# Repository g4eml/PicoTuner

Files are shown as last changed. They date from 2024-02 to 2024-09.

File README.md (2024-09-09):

# PicoTuner
## Description

This design is for a Raspberry Pi Pico based USB interface for the BATC Minitiouner V3 Digital TV Receiver.
It is intended to replace the previously used FTDI FT2232H module which is expensive and sometimes difficult to obtain. 
The Raspberry Pi Pico is low cost, readily available and can also handle both Transport streams from the NIM module. 

## Requirements

This code will work on the original Raspberry Pi Pico, the Pico W, the Pico 2 and probably on other RP2040 and RP2350 based boards.
Whilst being designed for the new BATC V3 Minitiouner project it is also possible to retrofit a Pico to the V2 Minitiouner.
The advantage of doing this is to provide access to the second Transport Stream from the NIM. This will allow two signals to be received at the same time.

## Limitations

The Pico hardware can only support USB 1.1 Full Speed mode which is up to 12 Mb/s. The FTDI module can support High speed mode which is much faster. For this reason the Pico is only able to support the low Sample rate DVBS transmissions commonly used for amateur radio. It is not able to receive the much higher SRs used by commercial TV.  The upper speed limit has not yet been fully defined but it is perfectly capable of receiving the QO-100 (SR1500) Beacon twice, using both TS. 

## Programming or updating the Raspberry Pi Pico (quick method)

This can be done either before or after the Pico has been fitted to the minitiouner, it makes no difference. Updating to a new firmware version is done the same way. 

The uf2 file (from Version 0.12 onwards) is compatible with both the Pico and the Pico 2. 

1. Locate the latest compiled firmware file 'PicoTuner_vxxx.uf2' which will be found here https://github.com/g4eml/PicoTuner/releases and save it to your desktop. 

2. Hold down the BOOTSEL button on the Pico while connecting it to your PC using its micro USB port. The Pico should appear as a USB disk drive on your PC.

3. Copy the .uf2 file onto the USB drive. The pico will recognise the file and immediately update its firmware, reboot and the PC should recognise a new USB device. 

## Building your own version of the firmware (longer method and not normally required)
The Raspberry Pi Pico is programmed using the Arduino IDE with the Earl F. Philhower, III   core. 

#### Installing the Arduino IDE

1. Download and Install the Arduino IDE 2.3.0 from here https://www.arduino.cc/en/software

2. Open the Arduino IDE and go to File/Preferences.

3. in the dialog enter the following URL in the 'Additional Boards Manager URLs' field: https://github.com/earlephilhower/arduino-pico/releases/download/global/package__index.json

4. Hit OK to close the Dialog.

5. Go to Tools->Board->Board Manager in the IDE.

6. Type “pico” in the search box.

7. Locate the entry for 'Raspberry Pi Pico/ by Earle F. Philhower, III' and click 'Install'
 
#### Downloading the Software.

1. Download the latest released source code .zip file from https://github.com/g4eml/PicoTuner/releases

2. Save it to a convenient location and then unzip it. 

#### Programming the Pico

1. Open the Arduino IDE and click File/Open

2. Navigate to the File PicoTuner/Picotuner.ino (downloaded in the previous step) and click Open.

3. Select Tools and make the following settings.

   Board: "Raspberry Pi Pico" or "Raspberry Pi Pico 2"

   Debug Level: "None"

   Debug Port: "Disabled"

   C++ Exceptions: "Disabled"
   
   Flash Size: "2Mb (no FS)" for the Pico or "4Mb (no FS)" for the Pico 2
   
   CPU Speed: "133MHz" for the Pico or "150MHz" for the Pico 2

   IP/Bluetooth Stack: "IPV4 Only"
   
   Optimise: "Small (-Os)(standard)"
   
   RTTI: "Disabled"
   
   Stack Protection: "Disabled"

   Upload Method: "Default (UF2)"
   
   USB Stack: "No USB"          *** Yes this is correct, we don't need any additional USB support, it is all handled by the program. 

5. Connect the Rasperry Pi Pico to the USB port while holding down the BOOTSEL button. 

6. Click Sketch/Upload.

The Sketch should compile and upload automatically to the Pico. If the upload fails you may need to disconnect the Pico and then hold down the BOOTSEL button while reconnecting. 

## Firmware description

The firmware is based on the Raspberry Pi foundation example code for a low level USB device. It adds additional changes to the device descriptors so that the device configuration is very close to that of the previoulsy used FTDI2232 module.

Control of the GPIO pins for I2C, for device control and for reading the two TS streams is done using PIO state machines which are defined in the .pio.h files. 
Note that these files are auto generated and should not be manually edited. If you need to change the PIO machines then you will need to edit the .pio files and recompile them. 
The .pio files are not visible in the Arduino IDE, you should use another text editor to work on them. When finished you should run the 'build_pio.bat' batch job to create the pio.h files. 

Both cores of the  or RP2350 chip are used. Core0 does most of the work including running the interrupt driven USB device. Core1 handles the task of handling the DMA, copying and reformatting of the TS data.
Note that both cores are fairly time critical. Adding debugging print statements will slow them down and cause errors with the USB device. 

## USB device description

The resulting USB device has been made to look very similar to the FTDI FT2232H and presents two interfaces.  This is so that any existing software can easily be adapted to work with the new device. 
It is however far from a full emulation of the FT2232H. Only those features need by the Minitiuoner are implemented. Some FTDI commands are acknowledged but do nothing. 

The device VID is 0x2E8A (Raspberry Pi Foundation)

The device PID is 0xBA2C 

The endpoints are as follows:-

On Interface 0:-

0x00 and 0x80 as output and input for device control. 

0x81 and 0x02 for I2C and GPIO control. Very loosly emulating the FTDI MPSSE device

On Interface 1:-

0x83 and 0x84 as Bulk transfer inputs for streaming TS2 and TS1. Sent 512 bytes at a time. Note that there is a 2 byte status word at the beginning of each 512 byte transfer which will nedd to be removed to reform the original TS. 

## USB Drivers

No special drivers are needed for Ryde or Portsdown. If you are using the Picotuner with Windows then you will need to load the WinUSB drivers using the Zadig program which can be downloaded from https://github.com/pbatard/libwdi/releases/tag/v1.5.0

Using Zadig you can now install the WinUSB driver for both of the USB interfaces presented by the Pico.




Note that you must load the driver for Interface 0 and Interface 1  as shown above. 

Once the correct drivers have been loaded the picotuner should appear under 'Universal Serial Bus Devices' in windows hardware manager. 

PicoTuner in Device Manager

# Adaptor PCB for Minitiouner

Adaptor_Small

Whilst the PicoTuner was designed for use in a new tuner design it can also be retrofitted to the BATC V2 Minitiouner and similar designs providing their FTDI modules are fitted in sockets. This involves removing the FTDI module, replacing it with an adaptor pcb and adding 5 wires to connect signals that are not present on the FTDI sockets. The advantage of doing this upgrade is to provide access to the second TS. When supported by the host software this then allows the reception of two signals at the same time. To save space and to try to make the module mechanically compatible surface mount techniques are used. However due to the large size of the components involved it is still easily assembled by hand.  

## What is needed to make the adaptor

Parts Small

PCB :- These will be available from the BATC shop, or you can get your own made using one of the Chinese PCB manufacturers. The Gerber files are include in the Adaptor Folder.

Raspberry Pi Pico :- Surface mount version without pin headers.<br />
The Pi Hut Part Number:- SC0915    Mouser Part Number :- 358-SC0915

2 x 26 way Dual row 2.54mm surface mount pin headers.<br /> 
Harwin Part Number:- M20-8761346   Mouser Part Number:- 855-M20-8761346   Farnell Part Number :- 3756209

1 x 5 way Single row 2.54mm through hole pin header.<br /> 
Harwin Part Number:- M20-9990545   Mouser Part Number:- 855-M20-9990545   Farnell Part Number :- 1022252

## Assembly instructions

Start with fitting the first of the 26 Way Dual row pin headers. Apply solder to one pad of the PCB and then tack the connector in place. Ensure that all of the pins are centrally aligned on the pads. Once you are happy with the position apply solder to all af the pads to fix the connector in position. Fit the second connector in the same way, checking the the spacing is correct to fit into the socket on the minitiouner before final soldering. If you align both connectors accurately on the pads this will be correct but you may wish to use a scrap of veroboard or someting similar to check the alignment. Once you are happy solder the second connector into place.

Lay the pico board directly onto the PCB and align the edges with the pads. Apply solder to the castelated edge of pin 1 to form a fillet of solder. Check the alignment of the board and adjust as necessary. When happy apply solder to all castellated holes. If possible leave the driled holes free of solder. This will simplify the fitting of the Ethernet module at a later date. 

Fit and solder the 5 way pin header. 

Underside Small
Topside Small

## Fitting to the BATC V2 Minitiouner

Remove the FTDI module from its socket. Plug the Pico adaptor PCB in its place. The USB connector should be very close to the same position and should still be accessable through the rear panel. 

Connect pin 5 of J1 on the adaptor module to pin 9 of U7 (74HC10) on the minitiouner board. The 74HC10 is no longer used, so it can be removed or left in place, it makes no difference. You can solder the wire directly to the pin of the chip, remove the chip and plug the wire into the socket or use a pin header. 

Connect pin 4 of J1 to pin 10 of U7 in the same way. 

74HC10 Small

The final three wires need to be connected between J1 and the 'TS1' connector on the minitiouner PCB. These wires are only required if you wish to use the second TS. 

Connect J1 Pin 1 to D7

Connect J1 pin 2 to CLK

Connect J1 pin 3 to VA

TS1 Small
Fitting Small

## Programming the Pico

Program the pico as described [above](#programming-or-updating-the-raspberry-pi-pico-quick-method).

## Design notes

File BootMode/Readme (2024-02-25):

Version 0.8 adds a new command which will force the PicoTuner to enter BOOTSEL mode ready for uploading new firmware. 
This is as an altenative to using the BOOTSEL button on the Pico. Useful to avoid opening the case. 
New command is the single character 0xBB sent to Endpoint 2. The Pico will then immediately enter BOOTSEL  mode. 
A python script and a windows batch file are provided to send the necessary command.

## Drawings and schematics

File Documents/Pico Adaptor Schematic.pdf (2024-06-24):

# Raspberry Pi Pico Adaptor for Minitiouner V2 Boards

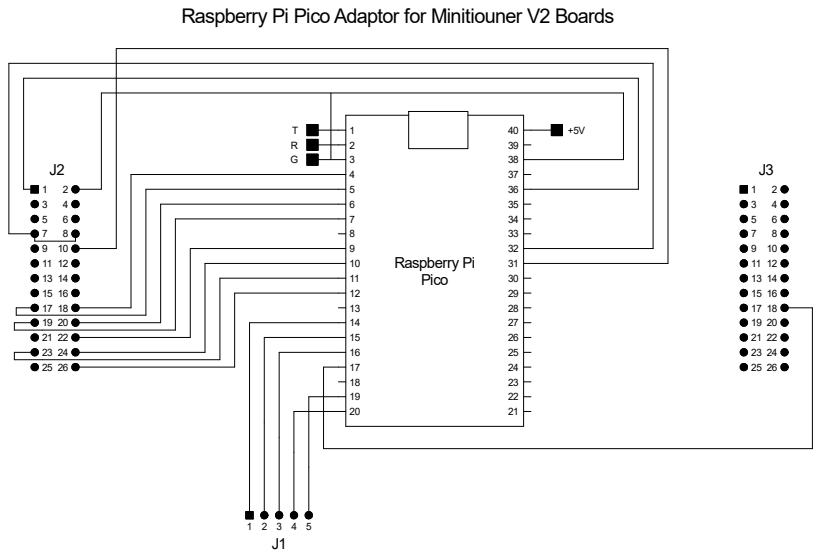
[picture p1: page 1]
Raspberry Pi Pico

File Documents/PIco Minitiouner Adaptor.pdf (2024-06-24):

## Pico Adaptor for Minitiouner V2

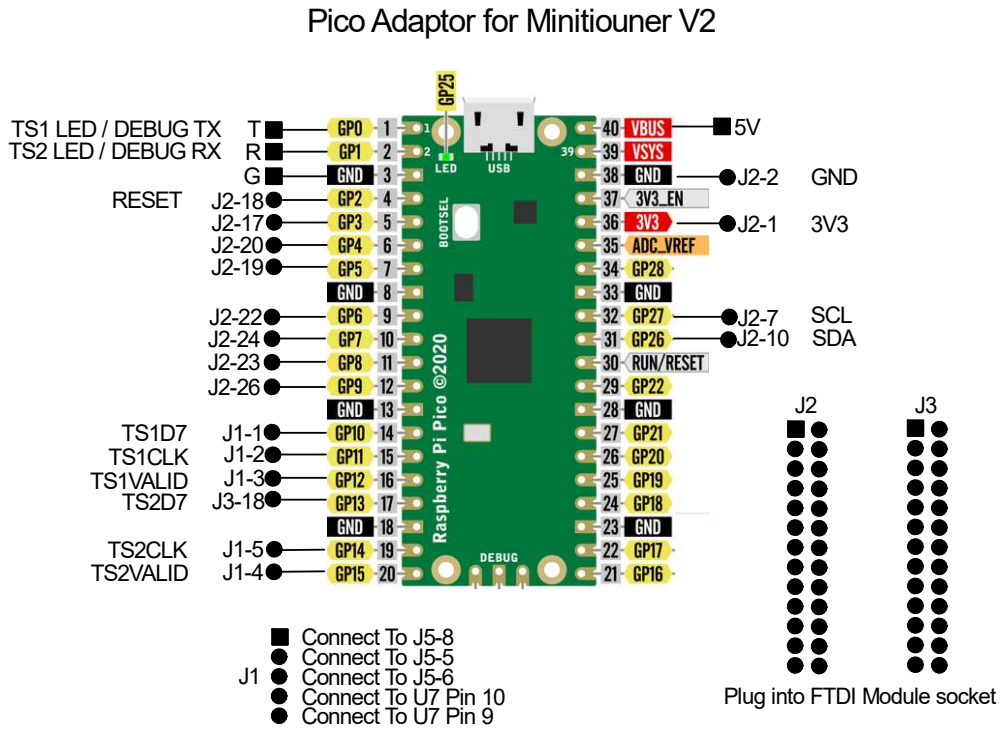
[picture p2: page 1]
TS1 LED / DEBUG TX; SDA; SCL; GND; RESET; TS1D7 TS1CLK TS1VALID; TS2CLK TS2VALID

TS2 LED / DEBUG RX

Connect To J5-8
Connect To J5-5
Connect To J5-6
Connect To U7 Pin 10
Connect To U7 Pin 9

Plug into FTDI Module socket

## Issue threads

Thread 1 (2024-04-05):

Pico ethernet

g6hfs, 2024-04-05:
Hi,

Is there any firmware info on ethernet port usage please.

Brian

g4eml, 2024-04-05:
Ethernet is not yet fully supported by my firmware. The Ethernet branch is experimental only and not for release. Brian G4EWJ is developing firmware using the ethernet port.  This is still in the early stages of testing. You would need to talk to him about that. Maybe in the future we will produce a combined firmware. Colin. On 5 Apr 2024 10:12, g6hfs ***@***.***> wrote:
Hi,
Is there any firmware info on ethernet port usage please.
Brian

—Reply to this email directly, view it on GitHub, or unsubscribe.You are receiving this because you are subscribed to this thread.Message ID: ***@***.***>

Closed 2024-04-05.

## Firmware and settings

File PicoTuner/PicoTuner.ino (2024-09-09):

/**
 * PicoTuner. 
 * BATC PicoTuner interface. 
 * Colin Durbridge G4EML January 2024.
 *
 * Provides a partial emulation of the FTDI FT2232 Dual port fifo chip. 
 * Only those functions used by the software are emulated.
 *
 * Written for the Arduino IDE using the RP2040 support developed by 
 * Earle F. Philhower, III.
 * See https://arduino-pico.readthedocs.io/en/latest/ for details. 
 * 
 * USB device is based on the Dev_Lowlevel example code provided by 
 * Copyright (c) 2020 Raspberry Pi (Trading) Ltd.
 * SPDX-License-Identifier: BSD-3-Claus
 * 
 * 
 */
// work around for Errata E15 in RP2040 datasheet. USB controller can lock up if a large bulk transfer is started near the end of a USB frame. 
// This fix limits tranfers to the first 80% of the frame time 

#define FIX_ERRATA_E15


//Version Number BCD   vvrr
#define VERSIONMAJOR 0
#define VERSIONMINOR 12                         
//Define the USB VID/PID values. 2E8A:BA2C uses the Raspberry Pi VID and a random PID. 
//Original FTDI chip uses 0403:6010
#define USBVID 0x2E8A
#define USBPID 0xBA2C

//BCDDEVICE is the device revision number. 
//0101 =Parallel TS      0102 =  Serial TS   
#define BCDDEVICE 0x0102       

//IO pin definitions.  Each group of pins must remain on sequential pins in the same order. The PIO hardware can only access sequential pins.  

#define DEBUG1 0          //Debug pin for Scope or terminal. Also used for Front Panel LEDs
#define DEBUG2 1          //Debug pin for scope or terminal. Also used for Front Panel LEDs

#define AC0 2         //NIM RESET LOW
#define AC1 3         //
#define AC2 4         //J8-6
#define AC3 5         //J8-5
#define AC4 6         //J8-4  LNB Bias Enable 
#define AC5 7         //J8-3 
#define AC6 8         //J8-2 
#define AC7 9         //J8-1  LNB BIAS Voltage Select


#define TS1DAT 10       //TS1 Data Bit (TS1D7)
#define TS1CLK 11       //TS1CLK
#define TS1VALID 12     //TS1VALID

#define TS2DAT 13     //TS2 Data bit (TS2D7)
#define TS2CLK 14     //TS2CLK 
#define TS2VALID 15   //TS2VALID

#define ETHSPRX 16    //Reserved for Ethernet Hat SPIO RX
#define ETHSPCS 17    //Reserved for Ethernet Hat SPIO CS Low
#define ETHSPCK 18    //Reserved for Ethernet Hat SPIO CLK               
#define ETHSPTX 19    //Reserved for Ethernet Hat SPIO TX
#define ETHRSTN 20    //Reserved for Ethernet Hat Reset Low                       
#define ETHINTN 21    //Reserved for Ethernet Hat Interrupt Low

#define ENA3V3 22    //Enable 3V3 Output. Set high when USB is fully initialised. 

#define LED 25         //Onboard LED

#define SDA 26         //AD1 SDA
#define SCL 27         //AD0 SCL

#define SPARE28 28


#include <hardware/pio.h>
#include "hardware/dma.h"
#include "hardware/irq.h"
#include <stdint.h>
#include <stdio.h>
#include "pico/stdlib.h"
#include <string.h>
#include "dev_lowlevel.h"

#include "Pio_Parallel_2.pio.h"
#include "Pio_Parallel_8.pio.h"
#include "Pio_TS_S.pio.h"

// variable for the start location of the State Machine programs
uint offset_2;
uint offset_8;
uint offset_TS1;
uint offset_TS2;

//variables for each state machine
PIO pioa = pio0;
uint sm_2 = 0;            //State machine for 3 bit port use state machine 0 on pio0
uint sm_TS1 = 3;          //TS1 Input Use State machine 3 on pio0
PIO piob = pio1;
uint sm_8 = 0;            //State machine for 8 bit port use state machine 0 on pio
uint sm_TS2 = 3;           //TS2 Input Use State machine 3 on pio1

#define TSPACKETLENW 47                               //47 32bit words equals one 188 byte TS packet. 
uint32_t TS2DMA[TSPACKETLENW];                        //DMA buffer for TS2 Packet              
uint32_t TS1DMA[TSPACKETLENW];                        //DMA buffer for TS1 Packet

uint DMA2Chan;
uint DMA1Chan;

bool TS2DMAAvailable = false;
bool TS1DMAAvailable = false;

int TS1ActiveTimeout = 0;
int TS2ActiveTimeout = 0;
unsigned long lastmillis =0;
#define TSTIMEOUT  20                //20 ms timeout for LEDs

//setup() initialises Core 0 of the RP2040.
//Core 0 does most of the work. 
void setup() 
{
   pinMode(DEBUG1,OUTPUT);
   pinMode(DEBUG2,OUTPUT);
   pinMode(LED,OUTPUT);

   //initialise pins for future Ethernet module
   pinMode(ETHSPTX,INPUT_PULLUP);
   pinMode(ETHSPRX,INPUT_PULLUP);
   pinMode(ETHSPCK,INPUT_PULLUP);
   pinMode(ETHSPCS,INPUT_PULLUP);
   pinMode(ETHINTN,INPUT_PULLUP);
   pinMode(ETHRSTN,OUTPUT);
   digitalWrite(ETHRSTN,LOW);

   //Configure the Power Control Pin
   
   pinMode(ENA3V3,OUTPUT);
   digitalWrite(ENA3V3,LOW);

   //initialise the PIO state machines

   // add the 3 bit port program and return its start location 
   offset_2 = pio_add_program(pioa, &Pio_Parallel_2_program);
   //initialse the PIO SM using the helper function defined in the .pio file
   Pio_Parallel_2_init(pioa, sm_2, offset_2, SDA);

   // add the 8 bit port program and return its start location 
   offset_8 = pio_add_program(piob, &Pio_Parallel_8_program);
   //initialse the PIO SM using the helper function defined in the .pio file
   Pio_Parallel_8_init(piob, sm_8, offset_8, AC0);


  // add the Serial input program and return its start location
   offset_TS1 = pio_add_program(pioa, &Pio_TS_S_program);
  //initialse the PIO SM using the helper function defined in the .pio file
    Pio_TS_S_init(pioa, sm_TS1, offset_TS1, TS1DAT);

  // add the Serial input program and return its start location
   offset_TS2 = pio_add_program(piob, &Pio_TS_S_program);
   //initialse the PIO SM using the helper function defined in the .pio file
   Pio_TS_S_init(piob, sm_TS2, offset_TS2, TS2DAT);

    irq_set_exclusive_handler(USBCTRL_IRQ,isr_usbctrl);    

   // reset all of the  buffers. 
    clearBuffers(0);

    for(int i=0;i<TSBUFNUM;i++)
      {
        TS2Buf[i][0] = 0xAA;                     //first two bytes of each 512 byte buffer are the FTDI status bits. 
        TS2Buf[i][1] = 0xAA;                     //We don't know what they do so just using 0xAA as a nominal value.
        TS1Buf[i][0] = 0xAA;                     //first two bytes of each 512 byte buffer are the FTDI status bits. 
        TS1Buf[i][1] = 0xAA;                     //We don't know what they do so just using 0xAA as a nominal value.   
      }


    usb_device_init();

    // Wait until configured
    while (!configured) {
        tight_loop_contents();
    }

    digitalWrite(ENA3V3, HIGH);

    // Get ready to rx MPSSE commands from host
    
    usb_start_transfer(usb_get_endpoint_configuration(EP2_OUT_ADDR), NULL, 64);

}

//loop() uses Core 0 of the RP2040
//Core 0 does most of the work.
void loop() 
{

#ifdef FIX_ERRATA_E15

    digitalWrite(LED , (lastUSBSOF & 0x40000) == 0);                 //flash the LED about 2 times per second clocked by the USB SOF interrupt 

   if(TS1Deferred > 0)                                  //if we have a deferred transfer waiting
     {
      sendTS1NI(TS1Deferred - 1);                        //try to send it
     }

   if(TS2Deferred > 0)                                  //if we have a deferred transfer waiting
     {
      sendTS2NI(TS2Deferred - 1);                        //try to send it
     }

  if(resultDeferred > 0)                                  //if we have a deferred transfer waiting
     {
      sendResult();                                       //try to send it
     }

#else

     digitalWrite(LED , (millis() & 0x100) ==0);                 //flash the LED about 2 times per second based on millis()

#endif



  if(commandsAvailable() > 0)
    {
      processCommands();
    } 


   if((TS2BufsAvailable() >= 1 )&&(!TS2TransferInProgress))       //wait till we have a 512 byte transfer like the FTDI chip does. 
  {
    sendTS2NI(TSNORMAL);
  }

  if((millis() > EP83Timeout)&&(!TS2TransferInProgress))       //send a status packet every 16ms and reset the TS state machine if we have not sent anything recently. 
  {
    sendTS2NI(TSSTATUS);
    dma_channel_set_irq0_enabled(DMA2Chan, false);
    dma_channel_abort(DMA2Chan);
    dma_channel_acknowledge_irq0(DMA2Chan);
    pio_sm_restart(piob, sm_TS2);
    dma_channel_set_irq0_enabled(DMA2Chan, true);
    dma_hw->ints0 = 1u << DMA2Chan;
    dma_channel_set_write_addr(DMA2Chan, TS2DMA, true);
    clearBuffers(2);
  }

   if((TS1BufsAvailable() >= 1 )&&(!TS1TransferInProgress))       //wait till we have a 512 byte transfer like the FTDI chip does. 
  {
    sendTS1NI(TSNORMAL);
  }

  if((millis() > EP84Timeout)&&(!TS1TransferInProgress))       //send a status packet every 16ms and reset the TS state machine if we have not sent anything recently. 
  {
    sendTS1NI(TSSTATUS);
    dma_channel_set_irq1_enabled(DMA1Chan, false);
    dma_channel_abort(DMA1Chan);
    dma_channel_acknowledge_irq1(DMA1Chan);
    pio_sm_restart(pioa, sm_TS1);
    dma_channel_set_irq1_enabled(DMA1Chan, true);
    dma_hw->ints1 = 1u << DMA1Chan;
    dma_channel_set_write_addr(DMA1Chan, TS1DMA, true);
    clearBuffers(1);
  }

  if(millis() > lastmillis)             //every millisecond
  {
    if(TS1ActiveTimeout > 0) TS1ActiveTimeout--;
    if(TS2ActiveTimeout > 0) TS2ActiveTimeout--;
    lastmillis = millis();
  }

  if(TS1ActiveTimeout > 0)
    {
      digitalWrite(DEBUG1,1);
    }
    else
    {
      digitalWrite(DEBUG1,0);
    }

  if(TS2ActiveTimeout > 0)
    {
      digitalWrite(DEBUG2,1);
    }
    else
    {
      digitalWrite(DEBUG2,0);
    }

}

//setup1() initialises Core 1 of the RP2040.
//Core 1 does the high priority work   
void setup1()
{
  //Setup DMA for TS2

  DMA2Chan = dma_claim_unused_channel(true);
 
  dma_channel_config c2 = dma_channel_get_default_config(DMA2Chan);

  channel_config_set_transfer_data_size(&c2, DMA_SIZE_32);
  channel_config_set_read_increment(&c2, false);
  channel_config_set_write_increment(&c2, true);
  channel_config_set_dreq(&c2, DREQ_PIO1_RX3);

  dma_channel_configure(
        DMA2Chan,               // Channel to be configured
        &c2,                    // The configuration we just created
        TS2DMA,                 // The initial write address the TS buffer
        &piob->rxf[sm_TS2],      // Source pointer
        TSPACKETLENW,            // Number of transfers
        false                    // do not start immediately.
    );
        
    dma_channel_set_irq0_enabled(DMA2Chan, true);      // Tell the DMA to raise IRQ line 0 when the channel finishes a block

 //Setup DMA for TS1

  DMA1Chan = dma_claim_unused_channel(true);
 
  dma_channel_config c1 = dma_channel_get_default_config(DMA1Chan);

  channel_config_set_transfer_data_size(&c1, DMA_SIZE_32);
  channel_config_set_read_increment(&c1, false);
  channel_config_set_write_increment(&c1, true);
   channel_config_set_dreq(&c1, DREQ_PIO0_RX3);

  dma_channel_configure(
        DMA1Chan,               // Channel to be configured
        &c1,                    // The configuration we just created
        TS1DMA,                 // The initial write address the TS buffer
        &pioa->rxf[sm_TS1],     // Source pointer
        TSPACKETLENW,           // Number of transfers
        false                    // do not start immediately.
    );
        
    dma_channel_set_irq1_enabled(DMA1Chan, true);      // Tell the DMA to raise IRQ line 1 when the channel finishes a block 

  //start the DMA transfers
    irq_set_exclusive_handler(DMA_IRQ_0, DMA2_handler);       // Configure the processor to run dma_handler() when DMA IRQ 0 is asserted
    irq_set_enabled(DMA_IRQ_0, true);

    DMA2_handler();        //manually call the handler once to start the transfers

    irq_set_exclusive_handler(DMA_IRQ_1, DMA1_handler);       // Configure the processor to run dma_handler() when DMA IRQ 1 is asserted
    irq_set_enabled(DMA_IRQ_1, true);

   DMA1_handler();        //manually call the handler once to start the transfers

}


//loop1() uses Core 1 of the RP2040
//Core 1 does the high priority work. Handles the DMA and re-formats the TS data from the PIO device and saves it to the TS buffers.
void loop1()
{
  union W
  {
    uint32_t w;                //map two variables to the same memory location
    uint8_t b[4];              //this allows access by 32bit word or by 4 8 bit bytes. 
  } wor;
                                                        
  if(TS2DMAAvailable)                     //have we received a new TS2 Packet?
    {
      TS2ActiveTimeout = TSTIMEOUT;
       for(int i=0; i < 47; i++)
         {
            wor.w = TS2DMA[i];                 //Get the next available 4 bytes of the TS packet  
            for(int b=3;b>=0;b--)                              //and copy them as bytes to the USB buffer. 
              {
                TS2Buf[TS2BufInNumber][TS2BufInPointer++] = wor.b[b];
                if(TS2BufInPointer >= TSBUFSIZE)               //if this buffer is full
                  {
                    TS2BufInPointer = 2;                       //move on to the next beffur
                    TS2BufInNumber++;
                    if(TS2BufInNumber >= TSBUFNUM) TS2BufInNumber = 0;
                  }
             }
         }
      TS2DMAAvailable = false;   
    }

  if(TS1DMAAvailable)                     //have we received a new TS1 Packet?
    {
      TS1ActiveTimeout = TSTIMEOUT;
       for(int i=0; i < 47; i++)
         {
            wor.w= TS1DMA[i];                 //Get the next available 4 bytes of the TS packet  
            for(int b=3;b>=0;b--)                              //and copy them to the buffer. 
              {
                TS1Buf[TS1BufInNumber][TS1BufInPointer++] = wor.b[b];
                if(TS1BufInPointer >= TSBUFSIZE)               //if this buffer is full
                  {
                    TS1BufInPointer = 2;                       //move on to the next beffur
                    TS1BufInNumber++;
                    if(TS1BufInNumber >= TSBUFNUM) TS1BufInNumber = 0;
                  }
             }
         }
      TS1DMAAvailable = false;   
    }

}                                                                                                 

//interrupt called when DMA for TS2 has completed. 
void DMA2_handler()
{
  // Clear the interrupt request.
    dma_hw->ints0 = 1u << DMA2Chan;
    // Give the channel a new write address, and re-trigger it
    dma_channel_set_write_addr(DMA2Chan, TS2DMA, true);
    TS2DMAAvailable = true;        //flag the data is avaiable. 
}

//interrupt called when DMA for TS1 has completed. 
void DMA1_handler()
{
  // Clear the interrupt request.
    dma_hw->ints1 = 1u << DMA1Chan;
    // Give the channel a new write address, and re-trigger it
    dma_channel_set_write_addr(DMA1Chan, TS1DMA, true);
    TS1DMAAvailable = true;        //flag the data is avaiable. 
}


void sendTS2NI(int mode)
{
  noInterrupts();
  sendTS2(mode);
  interrupts();
}

void sendTS1NI(int mode)
{
  noInterrupts();
  sendTS1(mode);
  interrupts();
}

void clearBuffers(int sel)
{
  if((sel == 2) || (sel == 0))
  {
    TS2BufInPointer = 2;
    TS2BufOutPointer = 0;
    TS2BufInNumber = 0;
    TS2BufOutNumber = 0;
  }


   if((sel == 1) || (sel == 0))
   {
    TS1BufInPointer = 2;
    TS1BufOutPointer = 0;
    TS1BufInNumber = 0;
    TS1BufOutNumber = 0;
   }


   if(sel == 0)
   {
    commandBufInPointer = 0;
    commandBufOutPointer = 0;
    resultBuf[0] = 0;               //It seems the FTDI Device adds a two byte header to all results. 
    resultBuf[1] = 0;               //We don't know what this should be but zeros seems to work with Longmynd
    resultBufCount = 2;             //
   }
}

//process all available MPSSE commands. 
//Only a few are relevent to the PicoTuner. The rest are ignored. 
void processCommands(void)
{
  int command;
  int param1;
  int param2;
  int param3;

  while(commandsAvailable() > 0)
  {
    command = getNextCommand();

    switch (command)
      {
        case 0xAA:                      //Special Bad Command for synchronising. Send response FA AA immediately.
          resultBuf[resultBufCount++] = 0xFA;
          resultBuf[resultBufCount++] = 0xAA;
          sendResult();
          break;

        case 0x80:                    //Set GPIO Low port 
          param1 = getNextCommand();  //pin values to set
          param2 = getNextCommand();  //pin direction 1=OUTPUT

          setGPIO(0,param1,param2);
          break;

        case 0x82:                    //Set GPIO High port 
          param1 = getNextCommand();  //pin values to set
          param2 = getNextCommand();  //pin direction 1=OUTPUT
          setGPIO(1,param1,param2);
          break;

        case 0x11:                    //Shift out 1 byte MSB first on negative edge of clock. 
          param1=getNextCommand();    //Length High
          param2=getNextCommand();    //Length Low. We only handle one byte at a time so we can ignore the length. 
          param3=getNextCommand();    //Byte
          shiftByteOut(param3);
          break;

        case 0x25:                    //Shift in 1 byte MSB first on negative edge of clock. (Datasheet says this should be 0x20 but Longmynd uses 0x25)
          param1=getNextCommand();    //Length High
          param2=getNextCommand();    //Length Low. We only handle one byte at a time so we can ignore the length. 
          shiftBitsIn(8);
          break;

        case 0x27:                    //Shift in 1 bit on negative edge of clock. (Datasheet says this should be 0x22 but Longmynd uses 0x27)
          param1=getNextCommand();    //number of bits. We only nedd to handle one bit for ACK so we can ignore this. 
          shiftBitsIn(1);
          break;

        case 0x87:                     //send result. Immediately send the current result buffer to host.
          sendResult();
          break;

        //single byte commands that we recognise but ignore because they are FTDI specific. 
        case 0x8A:                    //Disable clock/5
        case 0x97:                    //Disable adaptive clock
        case 0x85:                    //No Loopback
        case 0x8D:                    //Disable 32 phase clock        
          break;

        //Three byte commands that we recognise but ignore because they are FTDI specific. 
        case 0x86:                    //Set Clock Divide
          param1=getNextCommand();
          param2=getNextCommand();
          break;

        // New command to return firmware version
        case 0xBA:
          resultBuf[resultBufCount++] = VERSIONMAJOR;
          resultBuf[resultBufCount++] = VERSIONMINOR;
          sendResult();
          break; 

        // New command to force Rp2040 into BOOTSEL mode for software update
        case 0xBB:
            reset_usb_boot(0,0);
          break; 
      
        //Unrecognised commands  all return Bad Command response
        default :
          resultBuf[resultBufCount++] = 0xFA;
          resultBuf[resultBufCount++] = command;
          sendResult();
          break;
      }

  }
}



//Using PIO state machines set the gpio port to value, set pin directions to direction, 1 = output. port 0=AD, 1=AC
 void setGPIO(int port, int value, int direction)
 {
  int invdir;
  int invval;
  switch(port)
    {
      case 0:
        invdir = ((direction & 0x01)<< 1) + ((direction & 0x02) >> 1);             //Swap the two bits of both Direction and Value so that SDA and SCL match the RP2040 Hardware pins. 
        invval = ((value & 0x01)<< 1) + ((value &0x02) >> 1);                     //This allows a possible future update to use the hardware I2C instead of bitbanging. 
        pio_sm_put_blocking(pioa, sm_2, (invdir << 2) + invval);
        break;

      case 1:
        pio_sm_put_blocking(piob, sm_8, (direction << 8) + value );
        break;
    }

 }




//shift in count bits MSB first.
void shiftBitsIn(int count)
{
  int val = 0;

//RP2350 PIO is faster than the RP2040 so we need a longer delay to get the correct SPI Speed. 
#if defined(PICO_RP2350)
#define SPIDEL 2
#else
#define SPIDEL 1
#endif

  noInterrupts();
  for(int c= count ; c > 0 ; c--)
    {
      pio_sm_put_blocking(pioa, sm_2, (0x02 <<2 ) + 0x02);            //set SCL High with SDA HI Z
      delayMicroseconds(SPIDEL);
      val=(val<<1) + (digitalRead(SDA) ? 1:0);                       //shift in the data bit
      pio_sm_put_blocking(pioa, sm_2, (0x02 <<2 ) + 0x00);            //set SCL Low with SDA HI Z
      delayMicroseconds(SPIDEL);
    }
   interrupts();
  resultBuf[resultBufCount++] = val;
}

//shift out one byte of data MSB first using the 3 bit State machine
void shiftByteOut(int byte)
{
  noInterrupts();
  for(int c= 8 ; c > 0 ; c--)
    {
      pio_sm_put_blocking(pioa, sm_2, (0x03 <<2 ) + ((byte & 0x80) ? 1:0));            //set SDA with SCL Low
      delayMicroseconds(SPIDEL);
      pio_sm_put_blocking(pioa, sm_2, (0x03 <<2 ) + ((byte & 0x80) ? 3:2));            //set SDA with SCL High
      delayMicroseconds(SPIDEL);
      pio_sm_put_blocking(pioa, sm_2, (0x03 <<2 ) + ((byte & 0x80) ? 1:0));            //set SDA with SCL LOW
      byte=byte<<1;
    }
   interrupts();

}

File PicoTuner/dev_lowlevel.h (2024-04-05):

/**
 * BATC Minitiouner V3 interface. 
 * Colin Durbridge G4EML January 2024.
 *
 * Provides a partial emulation of the FTDI FT2232 Dual port fifo chip. 
 * Only those functions used by the Minitiouner are emulated.
 *
 * Written for the Arduino IDE using the RP2040 support developed by 
 * Earle F. Philhower, III.
 * See https://arduino-pico.readthedocs.io/en/latest/ for details. 
 * 
 * USB device is based on the Dev_Lowlevel example code provided by 
 * Copyright (c) 2020 Raspberry Pi (Trading) Ltd.
 * SPDX-License-Identifier: BSD-3-Claus
 * 
 * 
 */


// Include descriptor struct definitions
#include "usb_common.h"
// USB register definitions from pico-sdk
#include "hardware/regs/usb.h"
// USB hardware struct definitions from pico-sdk
#include "hardware/structs/usb.h"
// For interrupt enable and numbers
#include "hardware/irq.h"
// For resetting the USB controller
#include "hardware/resets.h"

// Device descriptors
#include "dev_lowlevel_descriptors.h"

#define usb_hw_set ((usb_hw_t *)hw_set_alias_untyped(usb_hw))
#define usb_hw_clear ((usb_hw_t *)hw_clear_alias_untyped(usb_hw))

// Function prototypes for our device specific endpoint handlers defined
// later on
void ep0_in_handler(uint8_t *buf, uint16_t len);
void ep0_out_handler(uint8_t *buf, uint16_t len);
void ep81_in_handler(uint8_t *buf, uint16_t len);
void ep2_out_handler(uint8_t *buf, uint16_t len);
void ep83_in_handler(uint8_t *buf, uint16_t len);
void ep84_in_handler(uint8_t *buf, uint16_t len);

void sendTS2(bool sendheader);
void sendTS1(bool sendheader);

void clearBuffers(int sel);

unsigned long EP83Timeout;
#define EP83TO 100      //timeout value in ms for EP83 packets. Will send a zero lenght packet if this timeout has expired. 
unsigned long EP84Timeout;
#define EP84TO 100       //timeout value in ms for EP83 packets. Will send a zero lenght packet if this timeout has expired. 


#ifdef FIX_ERRATA_E15

unsigned long lastUSBSOF = 0;             //time that we received the last USB Start of Frame in us (should be every 1000 us)
int TS1Deferred = 0;
int TS2Deferred = 0;
int resultDeferred = 0;

#endif

// Global device address
bool should_set_address = false;
uint8_t dev_addr = 0;
volatile bool configured = false;

// Global data buffer for EP0
uint8_t ep0_buf[64];

//Global buffer for MPSSE commands from Host 

#define COMMANDBUFSIZE 65536                        //probably much too big but we do have a lot of commands on retuning so better safe than sorry.
uint8_t commandBuf[COMMANDBUFSIZE];               
uint32_t commandBufInPointer;
uint32_t commandBufOutPointer;

//Global buffer for MPSSE results to Host
uint8_t resultBuf[1024];                             //allow for more than one packet of result data (unlikely but possible)
uint16_t resultBufCount;
volatile bool resultSent;

//Global circular buffer for TS data to Host
#define TSBUFSIZE 512  
#define TSBUFNUM 20                                 //This is the buffer size used by Longmynd It is Unlikely that we ever get near this value          
uint8_t TS2Buf[TSBUFNUM][TSBUFSIZE];                //20 512 byte buffers. 
uint16_t TS2BufInPointer;
uint16_t TS2BufOutPointer;
uint16_t TS2BufInNumber;
uint16_t TS2BufOutNumber;
uint8_t TS1Buf[TSBUFNUM][TSBUFSIZE];                //20 512 byte buffers. 
uint16_t TS1BufInPointer;
uint16_t TS1BufOutPointer;
uint16_t TS1BufInNumber;
uint16_t TS1BufOutNumber;

#define TSZLP 0
#define TSSTATUS 1
#define TSNORMAL 2


volatile bool TS2TransferInProgress = false;
volatile bool TS1TransferInProgress = false;
volatile bool TS2shortPacketSent = false;
volatile bool TS1shortPacketSent = false;

// Struct defining the device configuration
struct usb_device_configuration dev_config = {
        .device_descriptor = &device_descriptor,
        .interface_descriptor1 = &interface_descriptor1,
        .interface_descriptor2 = &interface_descriptor2,
        .config_descriptor = &config_descriptor,
        .lang_descriptor = lang_descriptor,
        .descriptor_strings = descriptor_strings,
        .endpoints = {
                {
                        .descriptor = &ep0_out,
                        .handler = &ep0_out_handler,
                        .endpoint_control = NULL, // NA for EP0
                        .buffer_control = &usb_dpram->ep_buf_ctrl[0].out,
                        // EP0 in and out share a data buffer
                        .data_buffer = &usb_dpram->ep0_buf_a[0],
                },
                {
                        .descriptor = &ep0_in,
                        .handler = &ep0_in_handler,
                        .endpoint_control = NULL, // NA for EP0,
                        .buffer_control = &usb_dpram->ep_buf_ctrl[0].in,
                        // EP0 in and out share a data buffer
                        .data_buffer = &usb_dpram->ep0_buf_a[0],
                },
                {
                        .descriptor = &ep81_in,
                        .handler = &ep81_in_handler,
                        // EP81 starts at offset 0 for endpoint control
                        .endpoint_control = &usb_dpram->ep_ctrl[0].in,
                        .buffer_control = &usb_dpram->ep_buf_ctrl[1].in,
                        // First free EPX buffer
                        .data_buffer = &usb_dpram->epx_data[0 * 64],
                },
                {
                        .descriptor = &ep2_out,
                        .handler = &ep2_out_handler,
                        .endpoint_control = &usb_dpram->ep_ctrl[1].out,
                        .buffer_control = &usb_dpram->ep_buf_ctrl[2].out,
                        // Second free EPX buffer
                        .data_buffer = &usb_dpram->epx_data[1 * 64],
                },
                {
                        .descriptor = &ep83_in,
                        .handler = &ep83_in_handler,
                        .endpoint_control = &usb_dpram->ep_ctrl[2].in,
                        .buffer_control = &usb_dpram->ep_buf_ctrl[3].in,
                        // third free EPX buffer
                        .data_buffer = &usb_dpram->epx_data[2 * 64],
                },
                {
                        .descriptor = &ep84_in,
                        .handler = &ep84_in_handler,
                        .endpoint_control = &usb_dpram->ep_ctrl[3].in,
                        .buffer_control = &usb_dpram->ep_buf_ctrl[4].in,
                        // fourth free EPX buffer
                        .data_buffer = &usb_dpram->epx_data[3 * 64],
                }
        }
};
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

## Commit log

2024-02-11 Change Device Name to PicoTuner
2024-02-15 Fix Buffer Overflow
    Command Buffer Overflow was possibly causing intermittent hangups.
    Buffer size increased.
    Also removed Assert() from USB code as this could also cause lockups.
    [PicoTuner.ino, dev_lowlevel.h]
2024-02-17 Add PCB Gerbers
2024-02-20 Swap Cores to try to fix hanging
    [PicoTuner.ino, dev_lowlevel.h]
2024-02-23 Speed Up I2C Comms
    I2c Speed increased to 400K . (maximum allowed in NIM datasheet.)
    Command Buffer size increased.
2024-02-24 V0-7
    Remove Static declarations and make them global.
    Tidy up some other changes.
    Seems to have fixed? the intermittent hangs.
    [PicoTuner.ino, dev_lowlevel.h, dev_lowlevel_descriptors.h]
2024-02-25 Add python script to force PicoTuner Into BOOTSEL mode without using the push button.
2024-02-25 V0.8
    Add new command 0xBB to force PicoTuner to switch to BOOTSEL mode for firmware updating.
    Useful to avoid needing to remove the case and press the BOOTSEL button.
    Python script provided to send the necessary command.
    [PicoTuner.ino]
2024-03-04 V0.9
    Add Power control output on GPIO 22.
2024-03-12 V0-10
    Fix DMA Error causing some lockups.
    [PicoTuner.ino, dev_lowlevel.h]
2024-04-05 V0-11
    Fix issue with low data rate TS streams.
    TS stream was timing out on low data rate streams. (333 1/3 or lower) . Timeout time increased to fix this.
    Checked OK down to 125 1/4 Operation now seems to be identical to FTDI module.
    [PicoTuner.ino, dev_lowlevel.h]
2024-06-24 Delete Documents/Pico Connections.pdf
    remove inaccurate document
2024-09-08 Add support for Pico 2
2024-09-08 Revert "Add support for Pico 2"
    This reverts commit a18e87e63235c66653d91917aa39ea2ed7d1bced.
    [PicoTuner.ino]
2024-09-08 Add Pico 2 support
2024-09-09 Adjust SPI Speed for Pico 2
